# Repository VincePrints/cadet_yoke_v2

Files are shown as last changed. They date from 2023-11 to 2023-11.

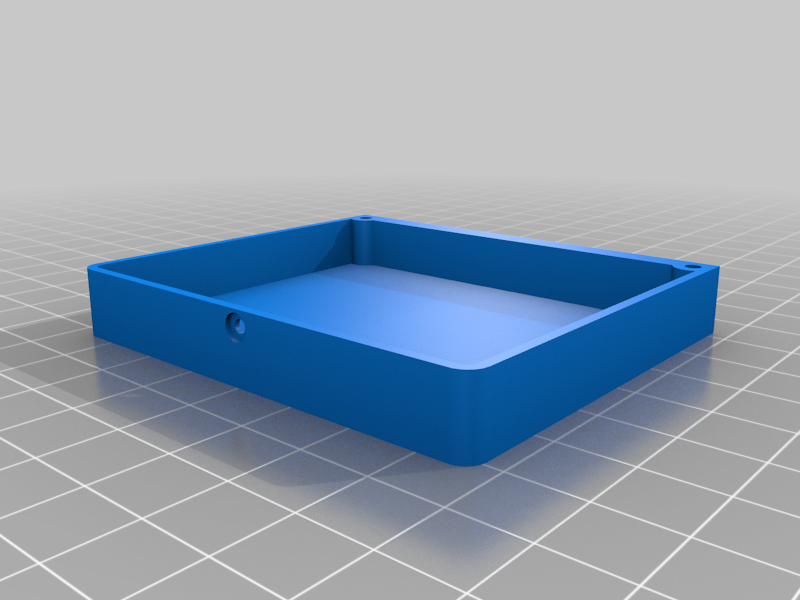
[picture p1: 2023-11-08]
images/Electronics_Housing_Base.png

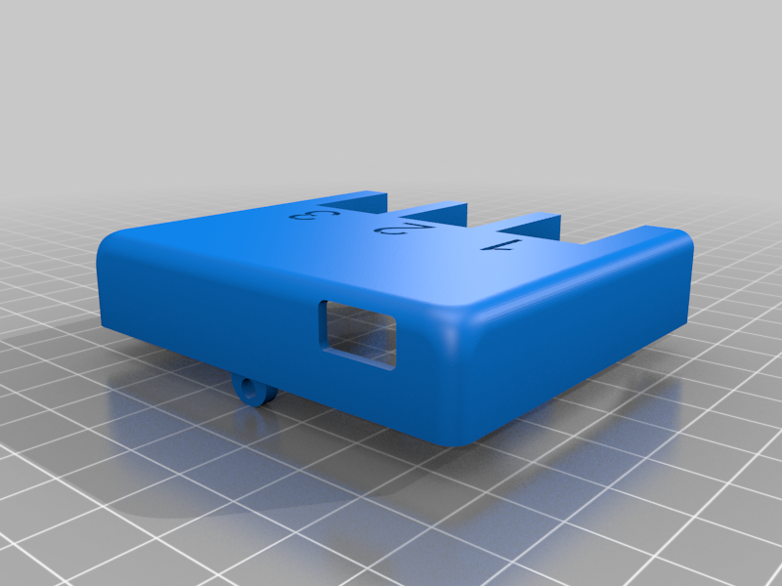
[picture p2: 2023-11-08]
images/Electronics_Housing_Lid.png

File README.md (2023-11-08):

# cadet_yoke_v2

This is an open-source yoke to be used with flight simulators!
- This thing was created by Thingiverse user Vince_Prints, and is licensed under Creative Commons - Attribution - Non-Commercial - Share Alike 

## Build Documentation
- User Guide: [User Guide](./User_Guide.pdf)
- Youtube: [YouTube link](https://www.youtube.com/watch?v=mIO1B-M6C_E)

## 3D Files
- Thingiverse: [Thingiverse link](https://www.thingiverse.com/thing:4884092)
- Printables: [Printables link](https://www.printables.com/model/68980-cadetyoke-v20-open-source-yoke-for-flight-simulato)

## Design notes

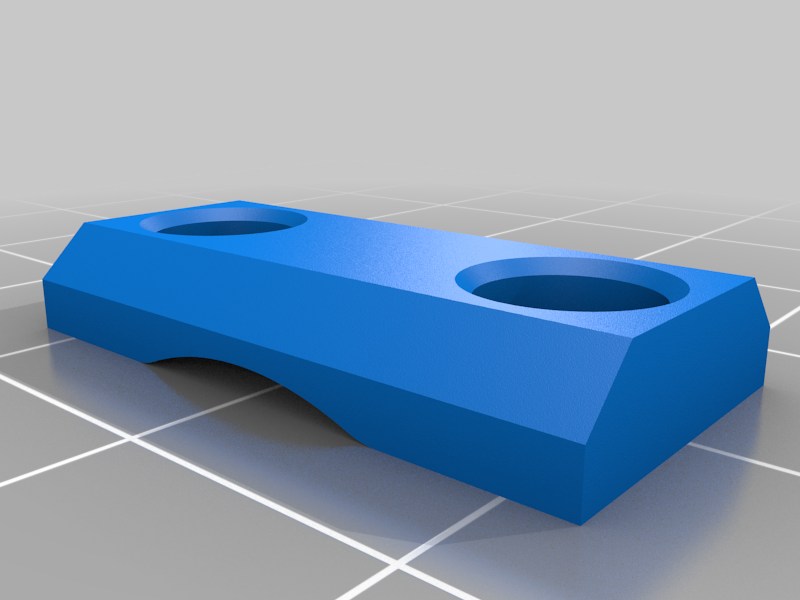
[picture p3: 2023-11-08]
images/Collar_Clip.png

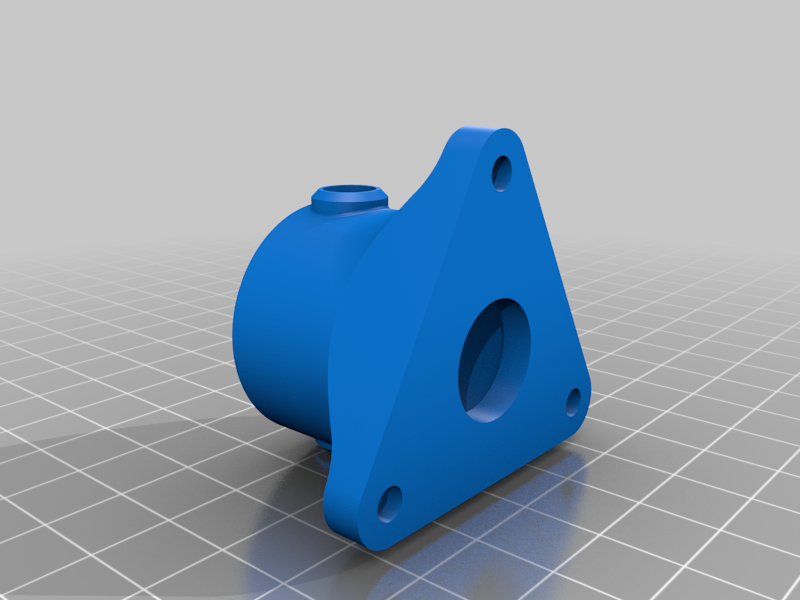
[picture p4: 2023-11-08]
images/Controller_Mount.png

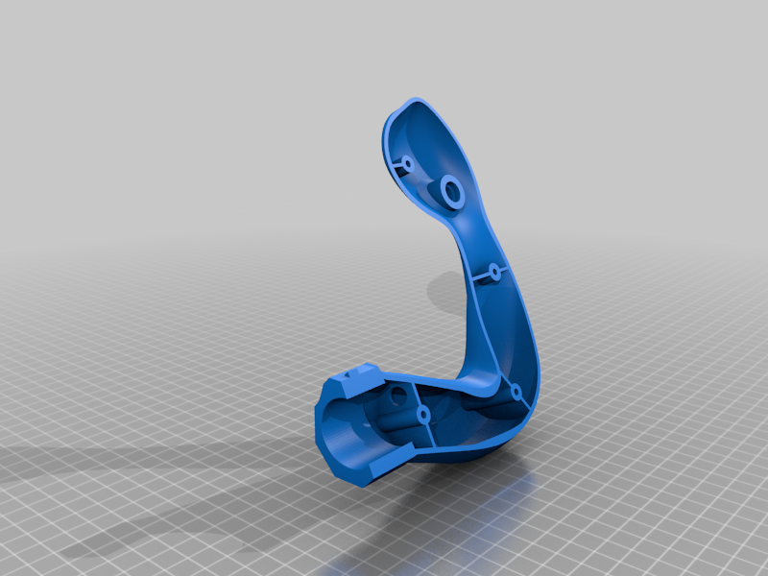
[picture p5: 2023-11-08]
images/Controller_RB.png

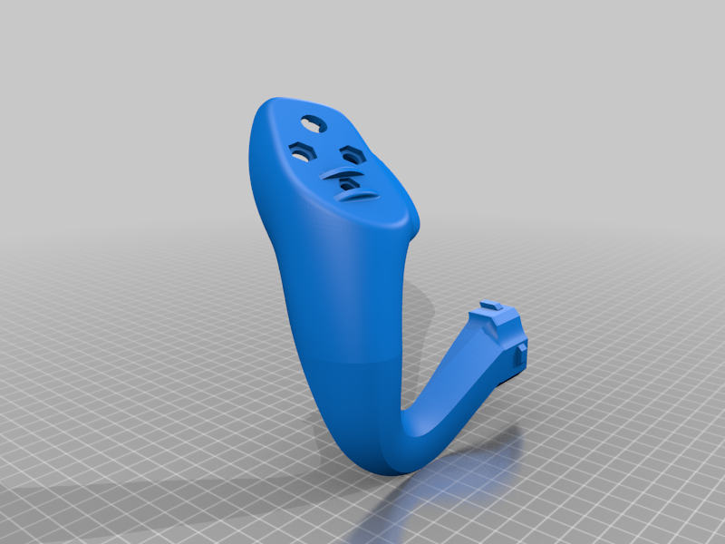
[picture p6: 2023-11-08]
images/Controller_LF.png

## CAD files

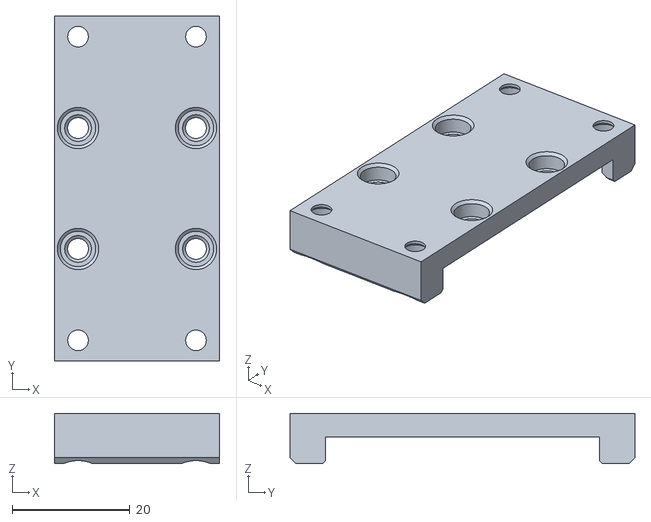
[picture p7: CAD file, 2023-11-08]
3D files/Linear_Rail_Mount.stl
28.0 x 58.5 x 8.50

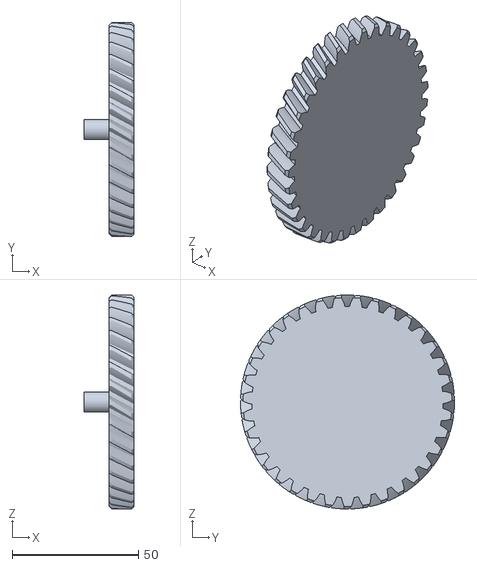
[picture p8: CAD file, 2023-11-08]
3D files/Helical_Pitch_Gear_35R.stl
20.0 x 84.8 x 84.8

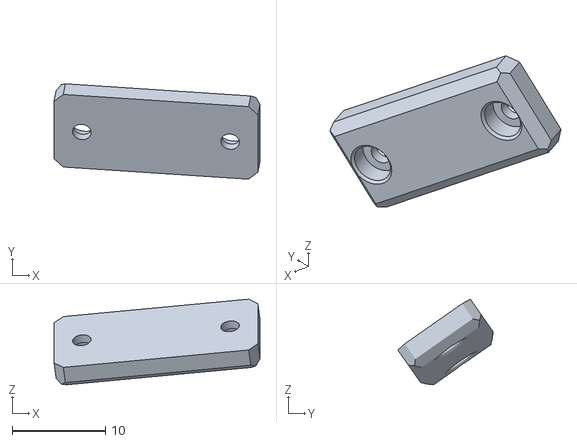
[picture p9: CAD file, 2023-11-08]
3D files/Hat_Switch_Mount.stl
22.1 x 10.2 x 9.18

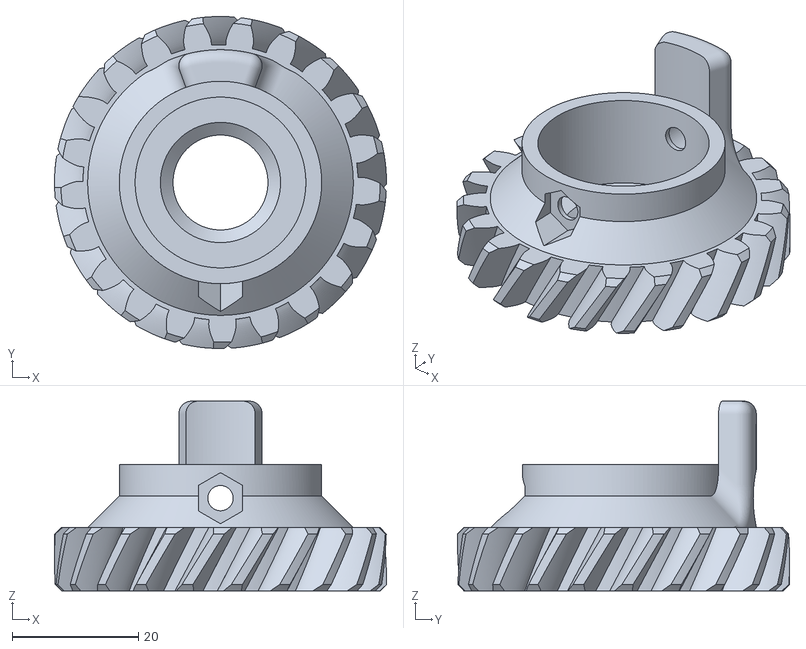
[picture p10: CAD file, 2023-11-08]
3D files/Helical_Roll_Gear_21R.stl
52.5 x 52.5 x 30.0

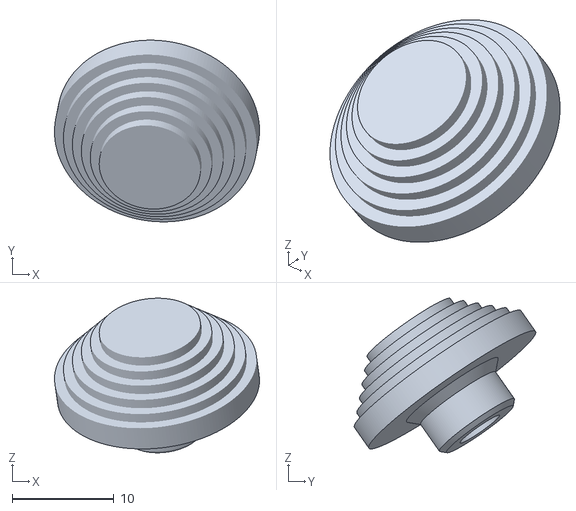
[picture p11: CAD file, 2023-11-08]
3D files/Hat_Switch_Topper.stl
20.2 x 17.9 x 15.2

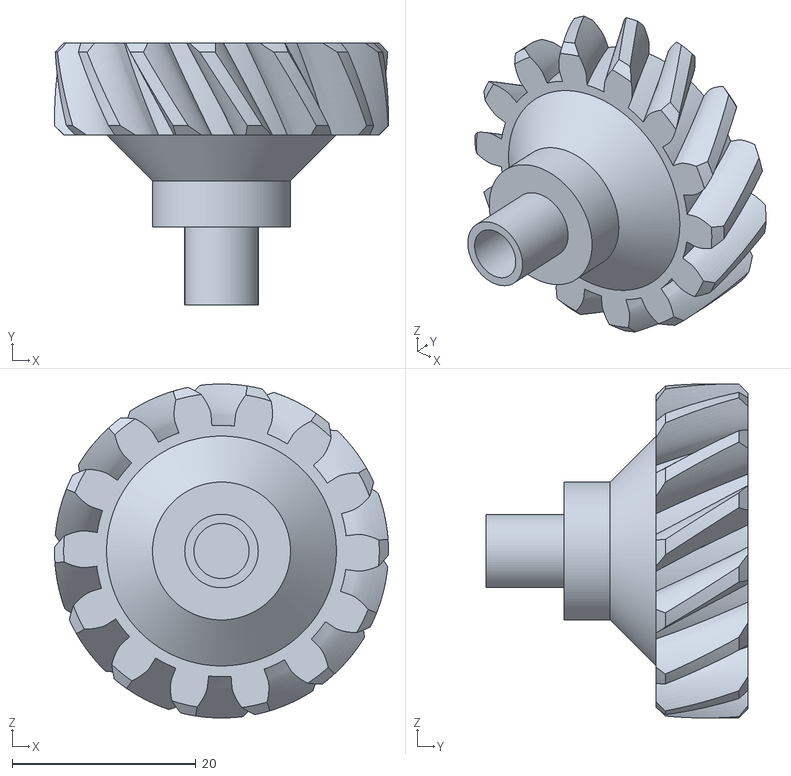
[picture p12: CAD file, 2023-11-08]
3D files/Helical_Roll_Gear__14L.stl
36.3 x 28.5 x 36.3

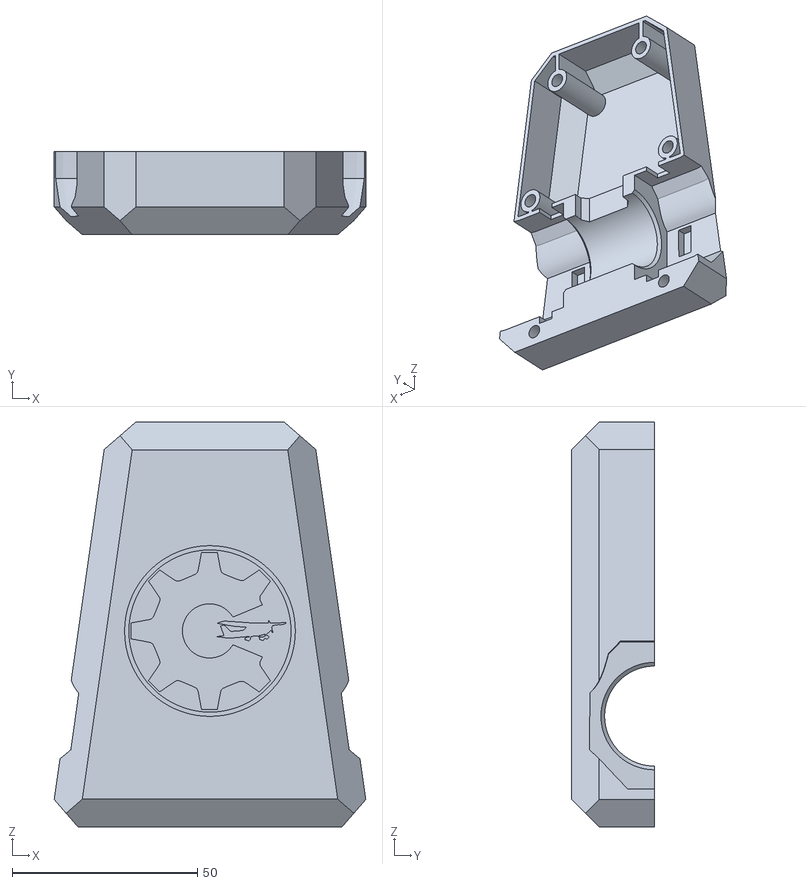
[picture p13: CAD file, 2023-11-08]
3D files/Console_Front.stl
84.1 x 22.5 x 109.3

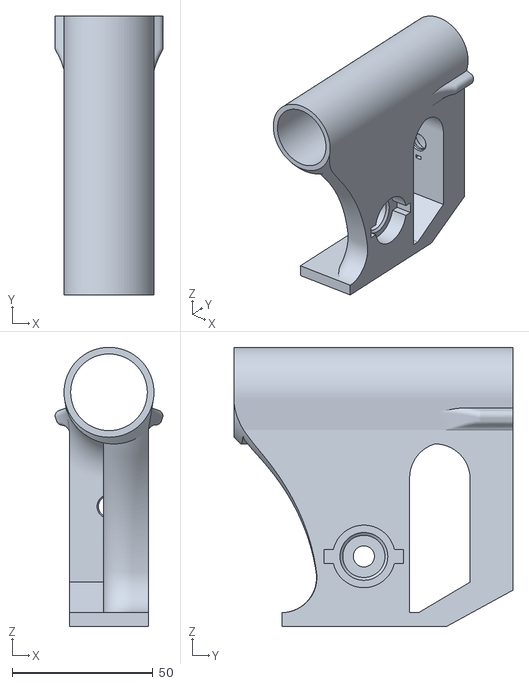
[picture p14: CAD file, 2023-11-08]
3D files/Linear_Rail_Body.stl
38.3 x 99.2 x 99.4

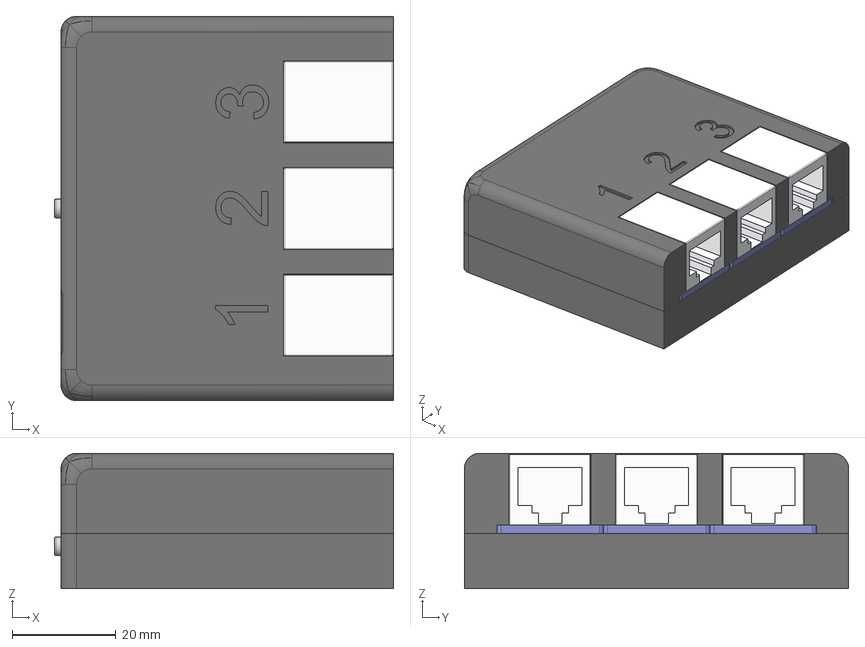
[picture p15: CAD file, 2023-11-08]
3D files/Electronics_Housing.step
65.3 x 74.0 x 26.1 mm
Lid
Base
M2x3 Threaded Insert x 3
M2x4 x 3
CAT5 x 3

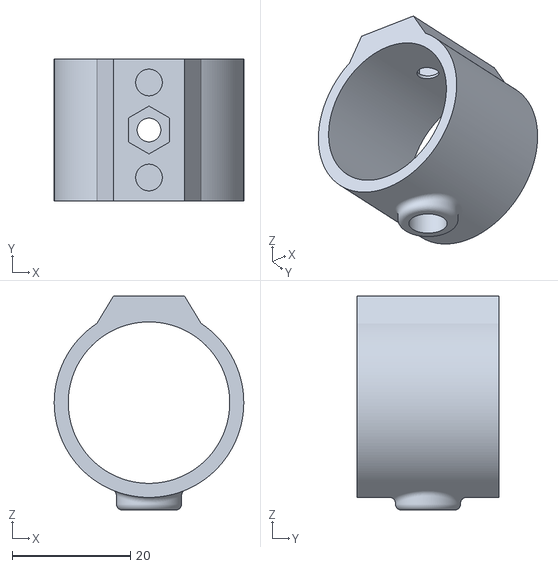
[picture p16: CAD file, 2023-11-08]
3D files/Centering_Collar.stl
32.0 x 24.0 x 36.1

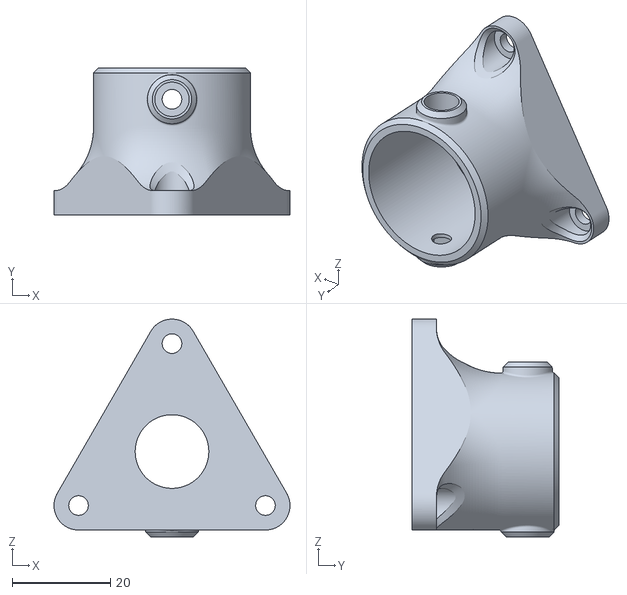
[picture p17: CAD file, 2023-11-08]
3D files/Controller_Mount.stl
48.1 x 30.0 x 44.4

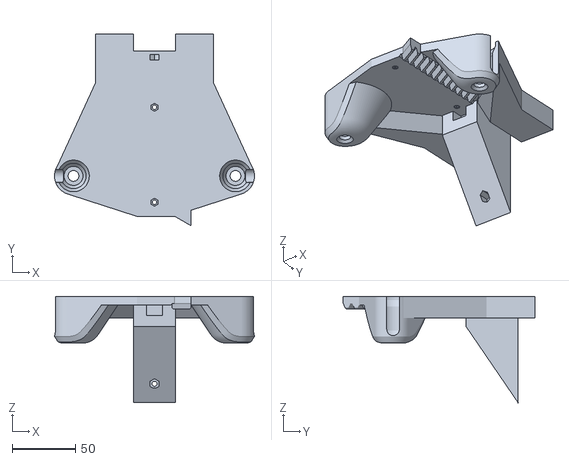
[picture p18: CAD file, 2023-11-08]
3D files/Base_Front.stl
158.0 x 151.4 x 84.0

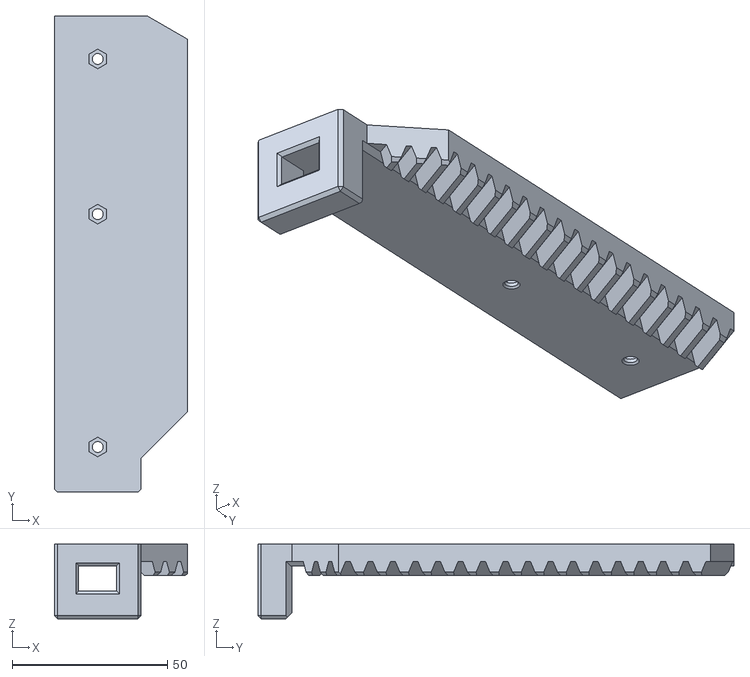
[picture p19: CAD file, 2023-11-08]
3D files/Base_Rear.stl
43.0 x 153.3 x 24.0

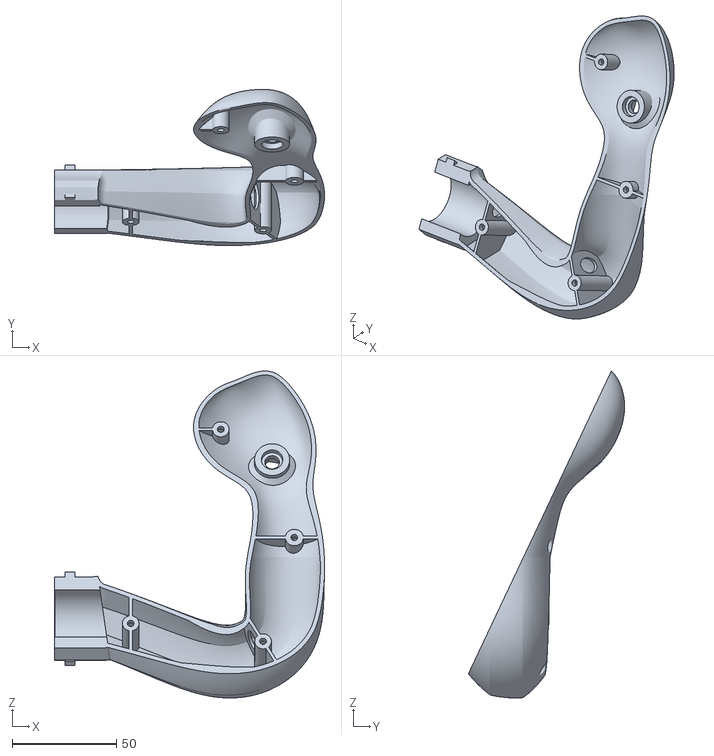
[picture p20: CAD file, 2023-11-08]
3D files/Controller_RB.stl
129.5 x 74.8 x 156.7

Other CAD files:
3D files/Console_Back.stl
3D files/Electronics_Housing_Lid.stl
3D files/Base_Guide.stl
3D files/Collar_Clip.stl
3D files/Controller_LB.stl
3D files/Electronics_Housing_Base.stl

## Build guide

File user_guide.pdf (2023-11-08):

CadetYokev2 Information

# Table of Contents:

Section: | Page #:
Code | 2
Bill of Materials (BOM) | 2 - 3
BOM Notes | 4
Wiring Diagram | 5 - 9
Printed Part Information | 10 - 31

BOM

# Arduino Code:

https://create.arduino.cc/editor/vince_prints/197730fc-074d-4160-bb42-757c4dfc1fe1/preview (https://create.arduino.cc/editor/vince_prints/197730fc-074d-4160-bb42-757c4dfc1fe1/preview)

Part: | Quantity: | Link: | Reused?:
Screws
M4 Nut | 8 | Amazon (https://www.amazon.com/gp/product/B071KBVZVV/ref=ppx_yo_dt_b_search_asin_title?ie=UTF8&psc=1) | All Projects
M4x30 (Socket Cap) | 3 | Amazon (https://www.amazon.com/gp/product/B071KBVZVV/ref=ppx_yo_dt_b_search_asin_title?ie=UTF8&psc=1) | All Projects
M4x10 (Socket Cap) | 3 | Amazon (https://www.amazon.com/gp/product/B071KBVZVV/ref=ppx_yo_dt_b_search_asin_title?ie=UTF8&psc=1) | All Projects
M4x18 (Socket Cap) | 2 | Amazon (https://www.amazon.com/gp/product/B071KBVZVV/ref=ppx_yo_dt_b_search_asin_title?ie=UTF8&psc=1) | All Projects
M3 Nut | 5 | Amazon (https://www.amazon.com/gp/product/B071KBVZVV/ref=ppx_yo_dt_b_search_asin_title?ie=UTF8&psc=1) | All Projects
M3x8 (Socket Cap) | 11 | Amazon (https://www.amazon.com/gp/product/B071KBVZVV/ref=ppx_yo_dt_b_search_asin_title?ie=UTF8&psc=1) | All Projects
M3x5 (Socket Cap) | 12 | Amazon (https://www.amazon.com/gp/product/B071KBVZVV/ref=ppx_yo_dt_b_search_asin_title?ie=UTF8&psc=1) | All Projects
M3x4 (Socket Cap) | 6 | Amazon (https://www.amazon.com/gp/product/B071KBVZVV/ref=ppx_yo_dt_b_search_asin_title?ie=UTF8&psc=1) | All Projects
M3x8 Threaded Brass Insert | 6 | Amazon (https://www.amazon.com/gp/product/B0784VYCYY/ref=ppx_yo_dt_b_search_asin_title?ie=UTF8&psc=1) | All Projects
M3x4 Threaded Brass Insert | 8 | Amazon (https://www.amazon.com/gp/product/B0784VYCYY/ref=ppx_yo_dt_b_search_asin_title?ie=UTF8&psc=1) | All Projects
M3x3 Threaded Brass Insert | 6 | Amazon (https://www.amazon.com/gp/product/B0784VYCYY/ref=ppx_yo_dt_b_search_asin_title?ie=UTF8&psc=1) | All Projects
M2x8 (Socket Cap) | 2 | Amazon (https://www.amazon.com/gp/product/B071KBVZVV/ref=ppx_yo_dt_b_search_asin_title?ie=UTF8&psc=1)
M2x4 (Socket Cap) | 3 | Amazon (https://www.amazon.com/gp/product/B071KBVZVV/ref=ppx_yo_dt_b_search_asin_title?ie=UTF8&psc=1) | All Projects
M2x3 Threaded Brass Insert | 5 | Amazon (https://www.amazon.com/gp/product/B0784VYCYY/ref=ppx_yo_dt_b_search_asin_title?ie=UTF8&psc=1) | All Projects

Electronics
Arduino Pro Micro | 1 | Amazon (https://www.amazon.com/gp/product/B07FXCTVQP/ref=ppx_yo_dt_b_search_asin_title?ie=UTF8&psc=1) | Salvaged from CadetYokev1
50x70mm Perf Board | 1 | Amazon (https://www.amazon.com/dp/B072Z7Y19F/ref=cm_sw_em_r_mt_dp_XC1HMP3KM1KTHSQAH6XX?_encoding=UTF8&psc=1) | All Projects
Female Pin Headers | 1 | Amazon (https://www.amazon.com/gp/product/B07CGGSDWF/ref=ppx_yo_dt_b_search_asin_title?ie=UTF8&psc=1) | All Projects
Large Momentary Pushbutton | 1 | Amazon (https://www.amazon.com/gp/product/B079D3ZZ1L/ref=ppx_yo_dt_b_search_asin_title?ie=UTF8&psc=1) | CadetThrottle

BOM

Small Momentary Pushbutton | 6 | Amazon (https://www.amazon.com/gp/product/B0752RMB7Q/ref=ppx_yo_dt_b_search_asin_title?ie=UTF8&psc=1) | Salvaged from CadetYokev1
Two-way Momentary Toggle Switch | 2 | Amazon (https://www.amazon.com/gp/product/B07VHCB1Q4/ref=ppx_yo_dt_b_search_asin_title?ie=UTF8&psc=1) | Salvaged from CadetYokev1
5-way Navigation Switch | 1 | Amazon (https://www.amazon.com/gp/product/B00E6QM2F0/ref=ppx_yo_dt_b_search_asin_title?ie=UTF8&psc=1)
Potentiometer (any value) | 2 | Amazon (https://www.amazon.com/gp/product/B07VJ57LJF/ref=ppx_yo_dt_b_search_asin_title?ie=UTF8&psc=1) | Salvaged from CadetYokev1
Diode (1N4007) | 16 | Amazon (https://www.amazon.com/gp/product/B00W17LOBO/ref=ppx_yo_dt_b_asin_title_o05_s00?ie=UTF8&psc=1)
10 ft. (~3m) CAT5e Cable | 1 | Amazon (https://www.amazon.com/Mediabridge-Ethernet-Cable-Feet-31-399-10X/dp/B003O973OA)
RJ45 8-pin Connector and Breakout Board | 3 | Amazon (https://www.amazon.com/gp/product/B08HGS5G8N/ref=ppx_yo_dt_b_asin_title_o08_s00?ie=UTF8&psc=1)
RJ45 Crimmping tool | 1 | Amazon (https://www.amazon.com/gp/product/B08DHJBLXQ/ref=ppx_yo_dt_b_asin_title_o07_s00?ie=UTF8&psc=1)
RJ45 Connectors | 3 | Amazon (https://www.amazon.com/gp/product/B08DHJBLXQ/ref=ppx_yo_dt_b_asin_title_o07_s00?ie=UTF8&psc=1)
RJ45 Covers | 3 | Amazon (https://www.amazon.com/gp/product/B08DHJBLXQ/ref=ppx_yo_dt_b_asin_title_o07_s00?ie=UTF8&psc=1)
Wire [1] | | Amazon (https://www.amazon.com/gp/product/B07G2GLKMP/ref=ppx_yo_dt_b_search_asin_title?ie=UTF8&psc=1) | All Projects
Mechanical Components
Linear Rail (250mm, H-Type) | 1 | Amazon (https://www.amazon.com/gp/product/B07GBNTJW3/ref=ppx_yo_dt_b_search_asin_title?ie=UTF8&psc=1) | Salvaged from CadetYokev1
Ball Bearings (608-2RS) | 2 | Amazon (https://www.amazon.com/gp/product/B07R7PR72H/ref=ppx_yo_dt_b_search_asin_title?ie=UTF8&psc=1) | Salvaged from CadetYokev1
3/4 in. PVC Pipe (350mm Length) [2] | 1
3/4 in. PVC Pipe (70mm Length) [3] | 1 | | Salvaged from CadetYokev1
Exercise Band (Green) | 1 | Amazon (https://www.amazon.com/gp/product/B0000AJ04V/ref=ppx_yo_dt_b_search_asin_title?ie=UTF8&th=1)
Zip ties [4] | | | All Projects
Mounting Clamps [5] | 2 | Amazon (https://www.amazon.com/gp/product/B093ND5KN5/ref=ppx_yo_dt_b_asin_title_o09_s00?ie=UTF8&th=1)

Notes

[1] User Preference
[2] !!!WARNING!!! In the US, 3/4 inch (19.05mm) describes the INNER diameter of the pipe, the outer diameter is 1.05 inches (26.67mm).
[3] !!!WARNING!!! In the US, 3/4 inch (19.05mm) describes the INNER diameter of the pipe, the outer diameter is 1.05 inches (26.67mm).
[4] User Preference
[5] User Preference

5-way tactile switch pinout

Notice spacing

Arduino Micro

Pin
Numbers

Button/Switch Reference

Pins

Common

(Shared by
both pins)

Pins

Signal
5V

GND

Diode Direction Reference

CAT5e Color Reference

In this guide, color
saturation will
indicate spiral
verses solid colors.

Example:

Spiral Orange:

Orange:

1
2

3

4
5

6

7 8 9 10 14

# #1 (Left Side)

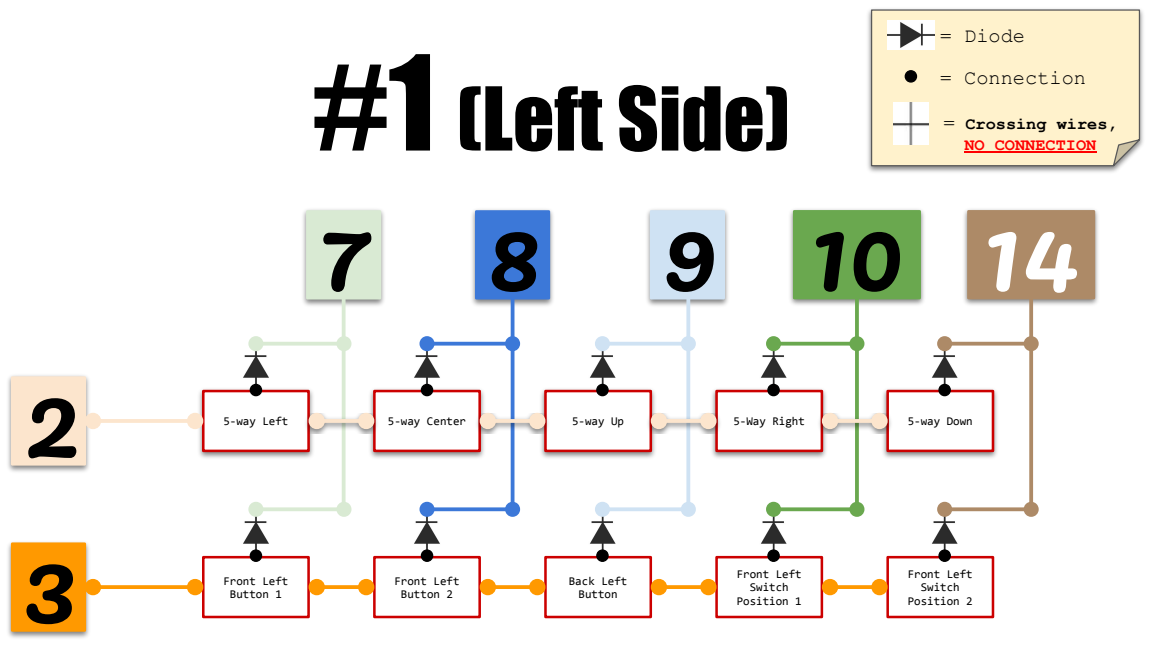
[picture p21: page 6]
5-way Left; 5-way Center; 5-way Up; 5-Way Right; 5-way Down; Front Left Button 1; Front Left Button 2; Back Left Button; Front Left Switch Position 1; Front Left Switch Position 2; = Diode; = Connection; = Crossing wires,; NO CONNECTION

15 16
45

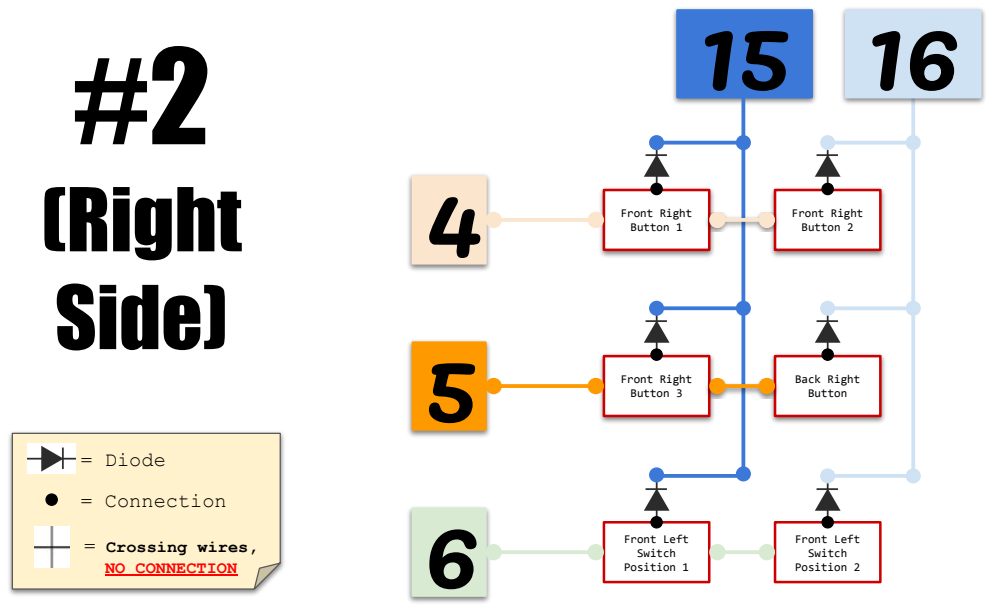
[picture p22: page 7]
Front Right Button 1; Front Right Button 2; Front Right Button 3; Back Right Button; (Right Side); = Diode; NO CONNECTION; Front Left Switch Position 1; Front Left Switch; Position 2

= Connection = Crossing wires,

# #3 (Pitch + Roll)

Roll | Pitch

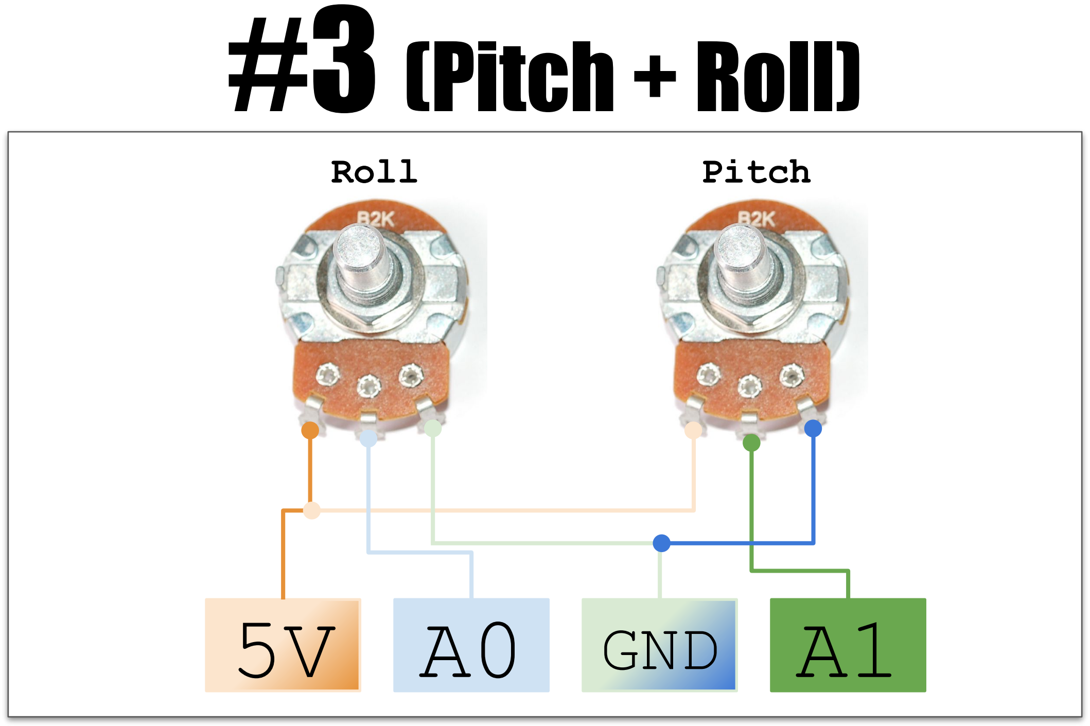
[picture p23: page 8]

5V | A0 | GND
A1

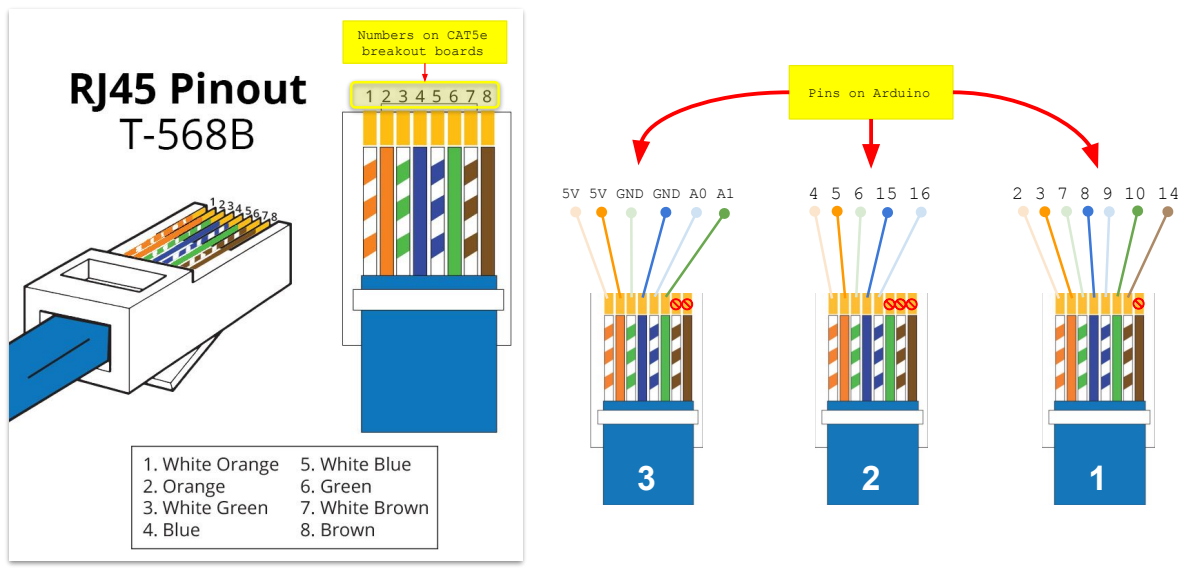
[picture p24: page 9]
5V 5V GND GND A0 A1; Numbers on CAT5e breakout boards

Pins on Arduino

Part: | Page #: | Approximate Mass (grams):
Base_Back | 11 | 36.15
Base_Front | 12 | 154.57
Base_Guide | 13 | 25.84
Centering_Collar | 14 | 7.65
Collar_Clip | 15 | 1.05
Console_Back | 16 | 52.10
Console_Front | 17 | 47.35
Controller_LB | 18 | 84.41
Controller_LF | 19 | 85.31
Controller_Mount | 20 | 13.66
Controller_RB | 21 | 84.41
Controller_RF | 22 | 83.53
Electronics_Housing_Base | 23 | 16.70
Electronics_Housing_Lid | 24 | 16.14
Hat_Switch_Mount | 25 | 0.72
Hat_Switch_Topper | 26 | 2.65
Helical_Pitch_Gear_35R | 27 | 29.33
Helical_Roll_Gear_14L | 28 | 7.00
Helical_Roll_Gear_21R | 29 | 14.19
Linear_Rail_Body | 30 | 87.25
Linear_Rail_Mount | 31 | 5.89
| Total Mass (grams): | 855.90

Base_Back (36.15g)
Filament: PETG
Layer Height: 0.2
Perimeters: 3
Infill: 15%
Supports: On build plate only

Print Orientation

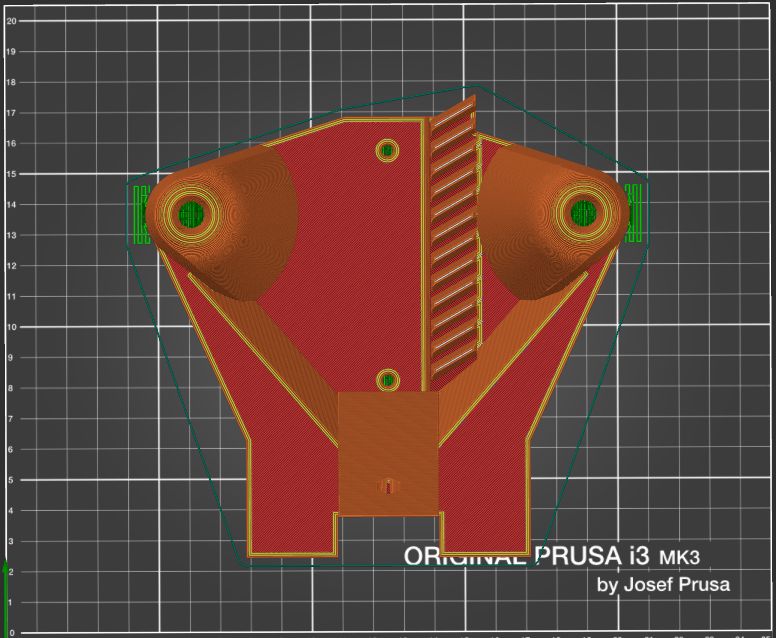
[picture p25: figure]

Base_Front (154.57g)
Filament: PETG
Layer Height: 0.2
Perimeters: 3
Infill: 15%
Supports: On build plate only

Print Orientation

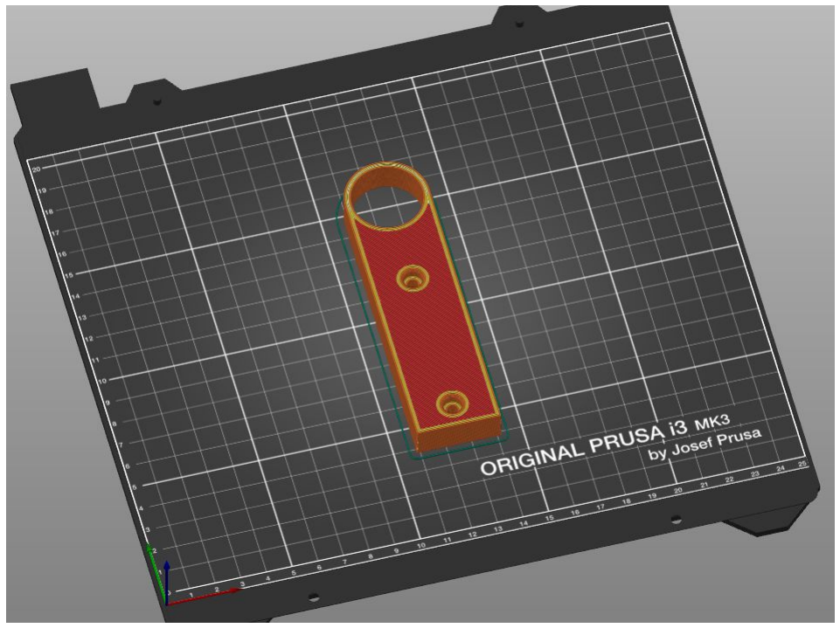
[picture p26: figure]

Base_Guide (25.84g)
Filament: PETG
Layer Height: 0.2
Perimeters: 3
Infill: 15%
Supports: None

Print Orientation

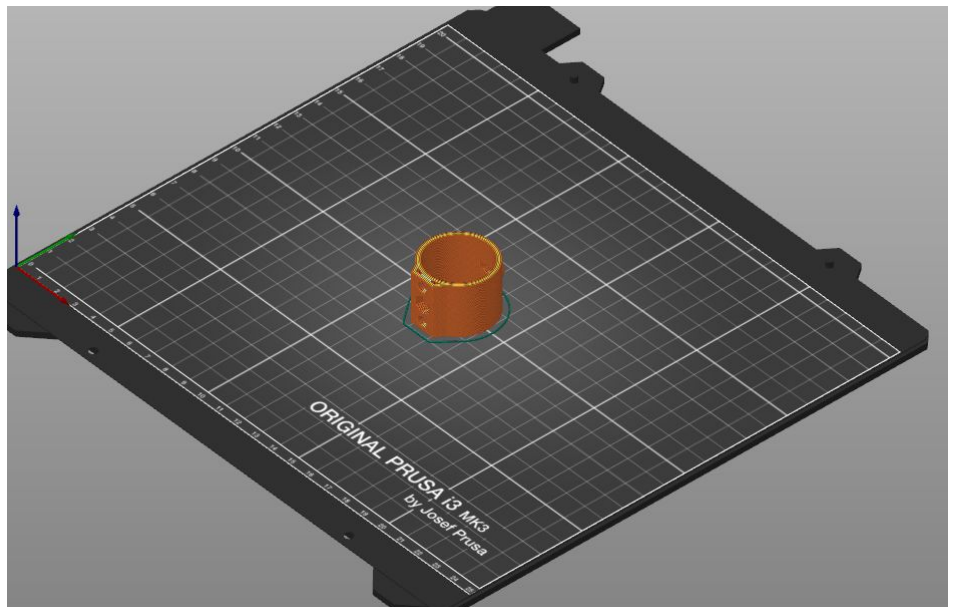
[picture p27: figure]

Centering_Collar (7.65g)
Filament: PETG
Layer Height: 0.2
Perimeters: 3
Infill: 15%
Supports: None

Print Orientation

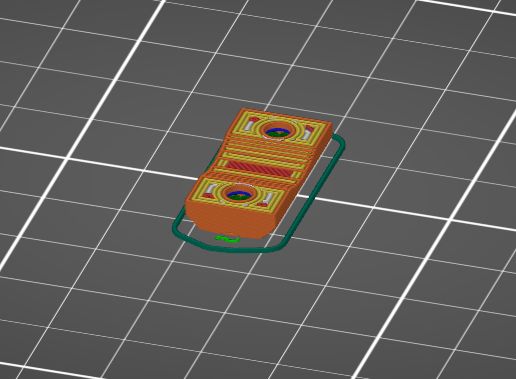
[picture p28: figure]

Collar_Clip (1.05g)
Filament: PETG
Layer Height: 0.2
Perimeters: 3
Infill: 15%
Supports: On build plate only

Print Orientation

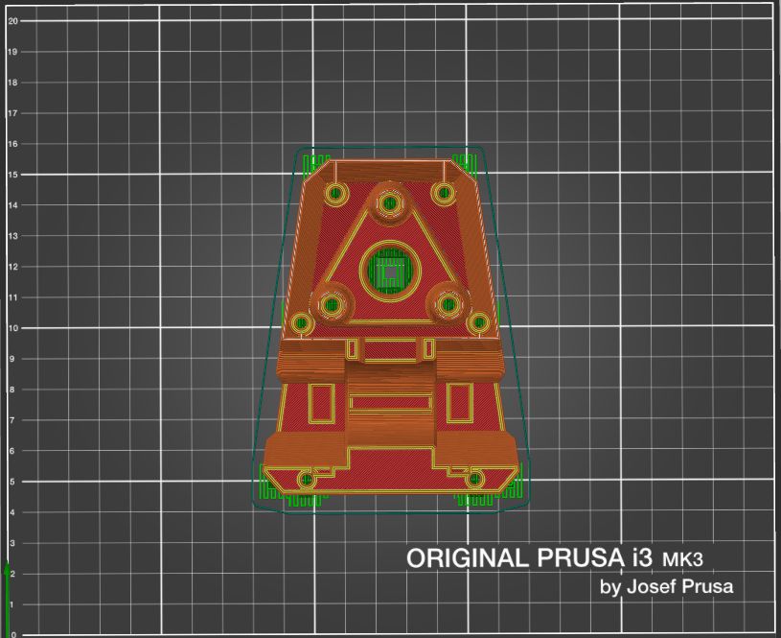
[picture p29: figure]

Console_Back (52.10g)
Filament: PETG
Layer Height: 0.2
Perimeters: 3
Infill: 15%
Supports: On build plate only

Print Orientation

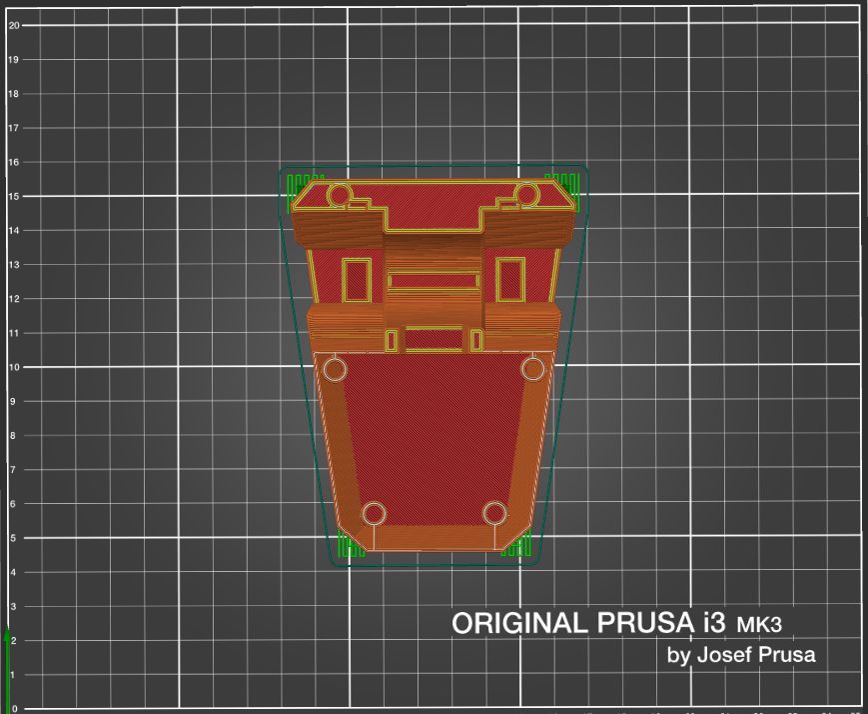
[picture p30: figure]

Console_Front (47.35g)
Filament: PETG
Layer Height: 0.2
Perimeters: 3
Infill: 15%
Supports: None

Print Orientation

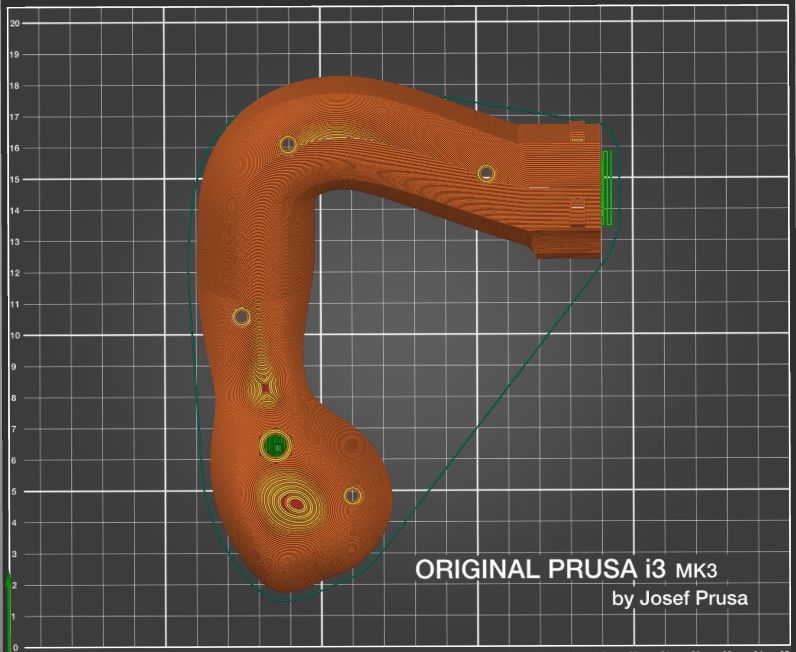
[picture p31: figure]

Controller_LB (84.41g)
Filament: PETG
Layer Height: 0.2
Perimeters: 3
Infill: 15%
Supports: On build plate only

Print Orientation

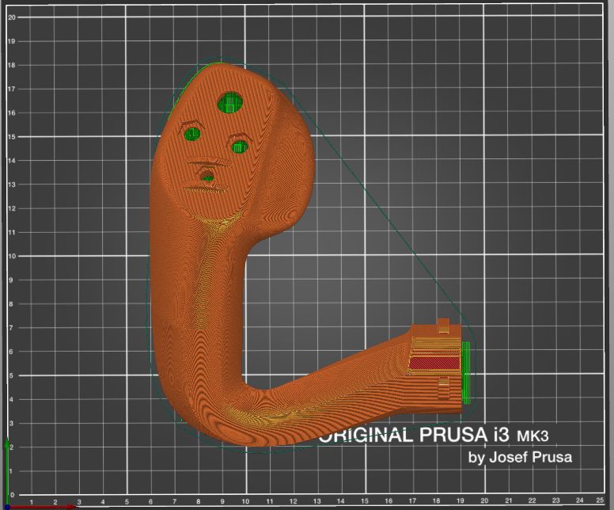
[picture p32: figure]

Controller_LF (85.31g)
Filament: PETG
Layer Height: 0.2
Perimeters: 3
Infill: 15%
Supports: On build plate only

Print Orientation

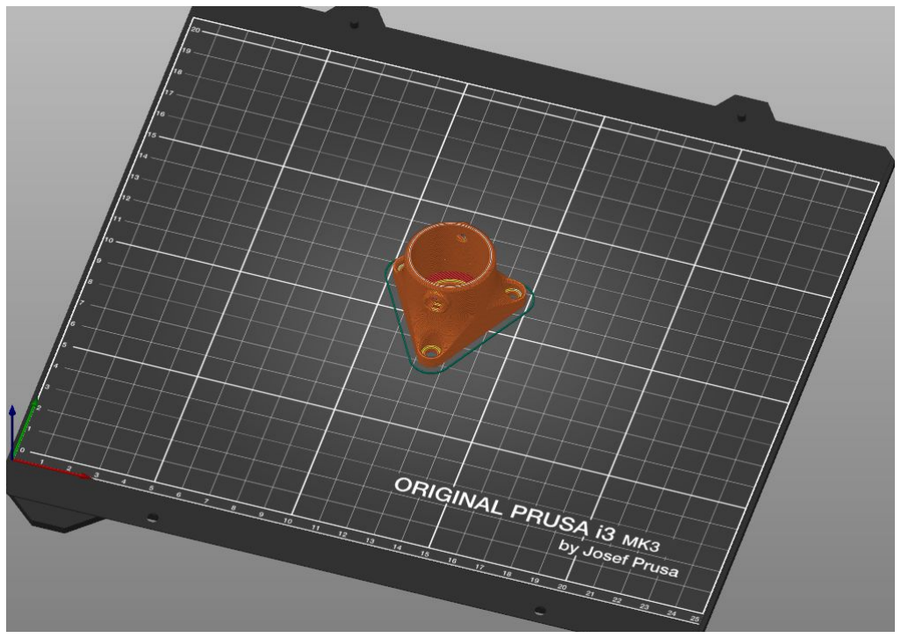
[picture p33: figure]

Controller_Mount (13.66g)
Filament: PETG
Layer Height: 0.2
Perimeters: 3
Infill: 15%
Supports: None

Print Orientation

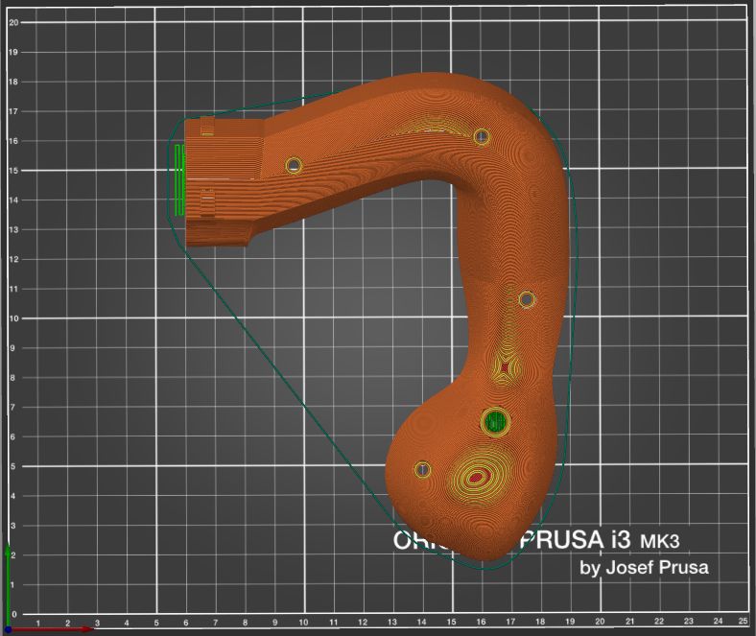
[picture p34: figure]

Controller_RB (84.41g)
Filament: PETG
Layer Height: 0.2
Perimeters: 3
Infill: 15%
Supports: On build plate only

Print Orientation

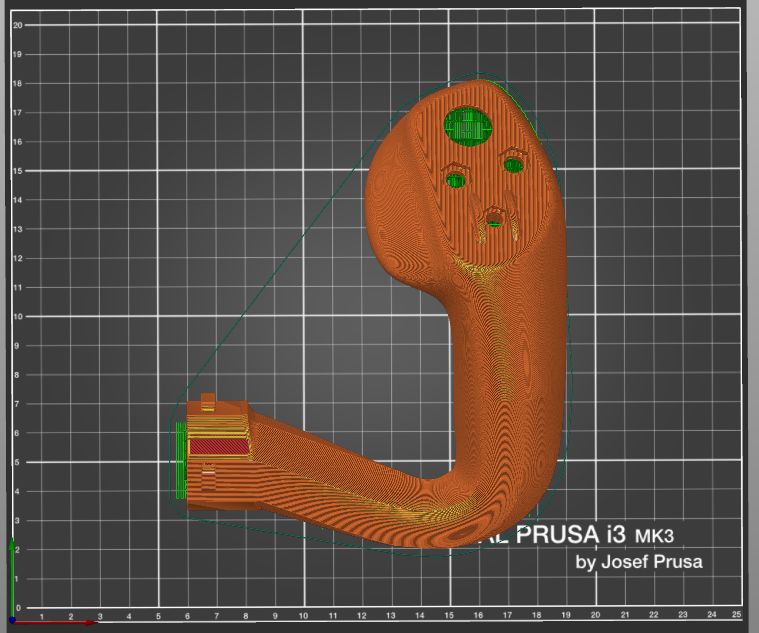
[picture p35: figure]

Controller_RF (83.53g)
Filament: PETG
Layer Height: 0.2
Perimeters: 3
Infill: 15%
Supports: On build plate only

Print Orientation

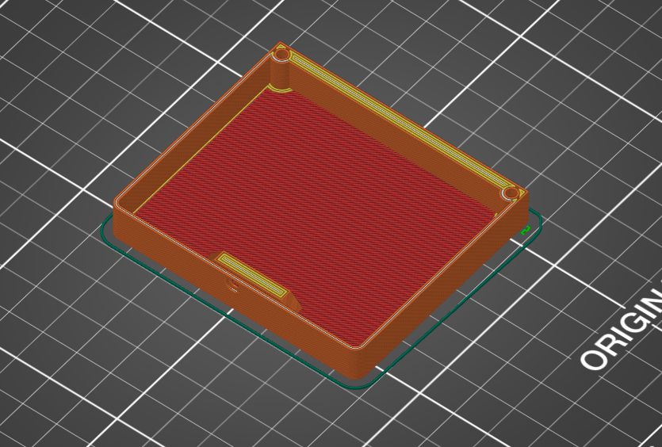
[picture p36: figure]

Electronics_Housing_Base (16.70g) Filament: PETG
Layer Height: 0.2
Perimeters: 3
Infill: 15%
Supports: On build plate only

Print Orientation

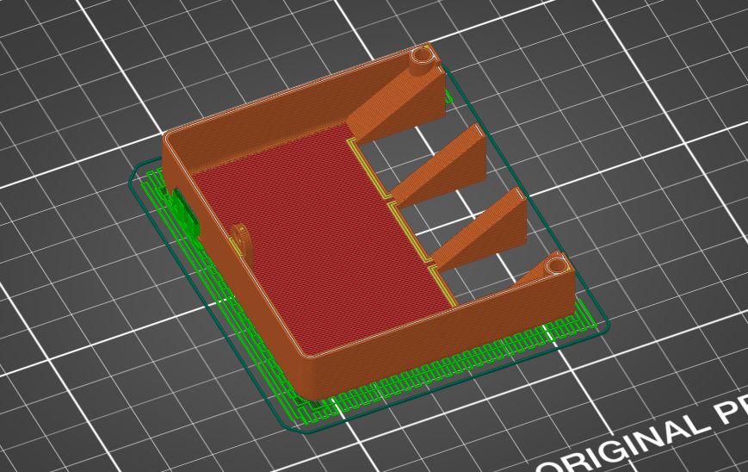
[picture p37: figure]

Electronics_Housing_Lid (16.14g) Filament: PETG
Layer Height: 0.2
Perimeters: 3
Infill: 15%
Supports: On build plate only

Print Orientation

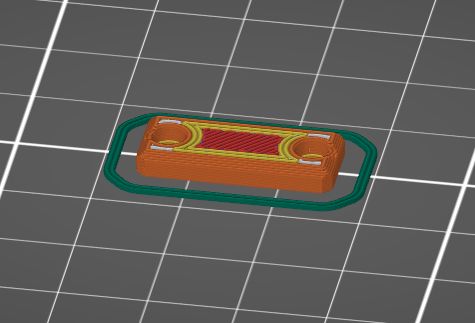
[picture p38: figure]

Hat_Switch_Mount (0.72g)
Filament: PETG
Layer Height: 0.2
Perimeters: 3
Infill: 15%
Supports: On build plate only

Print Orientation

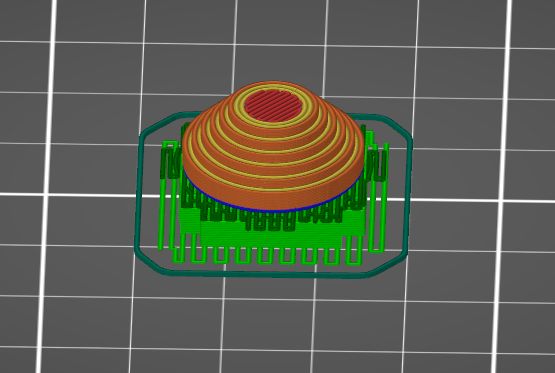
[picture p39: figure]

Hat_Switch_Topper (2.65g)
Filament: PETG
Layer Height: 0.2
Perimeters: 3
Infill: 15%
Supports: On build plate only

Print Orientation

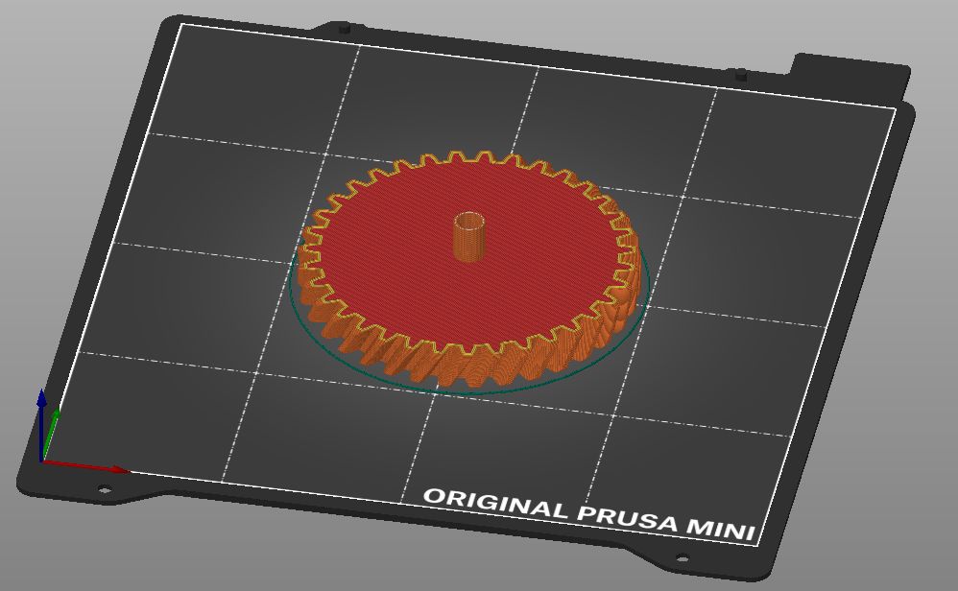
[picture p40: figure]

Helical_Pitch_Gear_35R(29.33g) Filament: PETG
Layer Height: 0.2
Perimeters: 3
Infill: 15%
Supports: None

Print Orientation

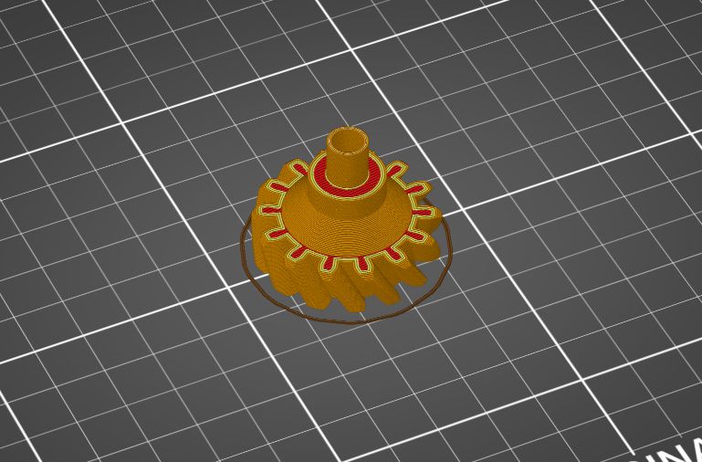
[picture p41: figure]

Helical_Roll_Gear_14L (7.00g) Filament: PETG
Layer Height: 0.2
Perimeters: 3
Infill: 15%
Supports: None

Print Orientation

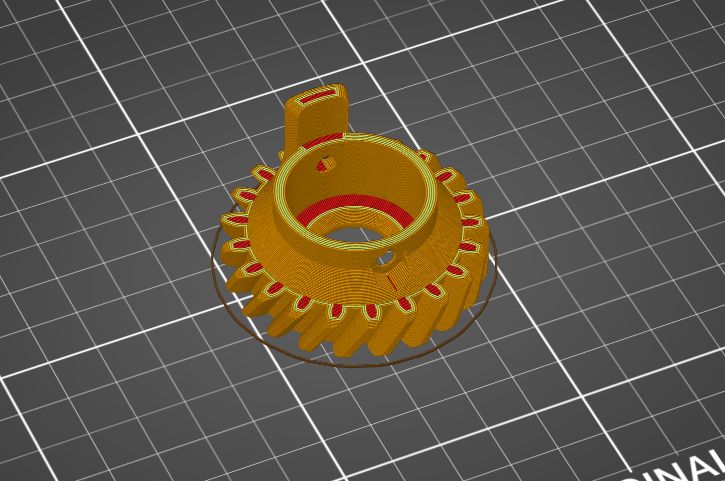
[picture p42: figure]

Helical_Roll_Gear_21R (14.19g) Filament: PETG
Layer Height: 0.2
Perimeters: 3
Infill: 15%
Supports: None

Print Orientation

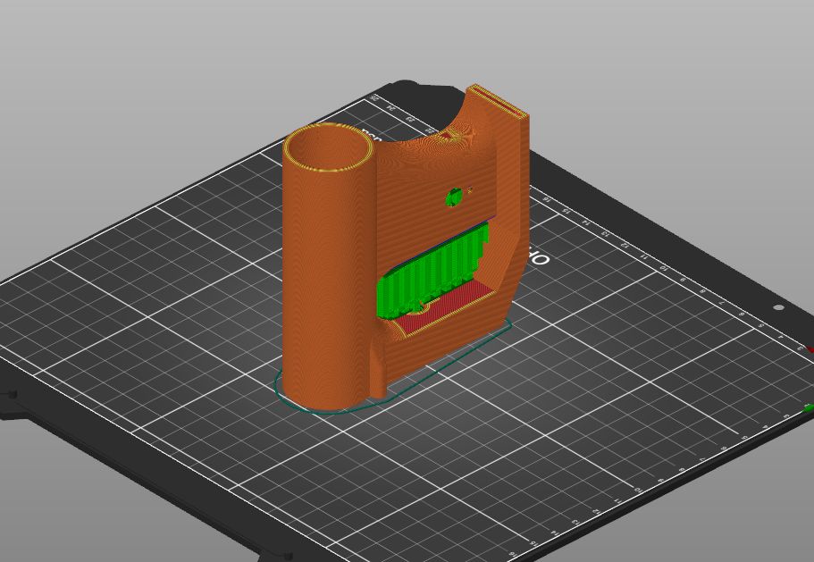
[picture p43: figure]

Linear_Rail_Body (87.25g)
Filament: PETG
Layer Height: 0.2
Perimeters: 3
Infill: 15%
Supports: Everywhere

Print Orientation

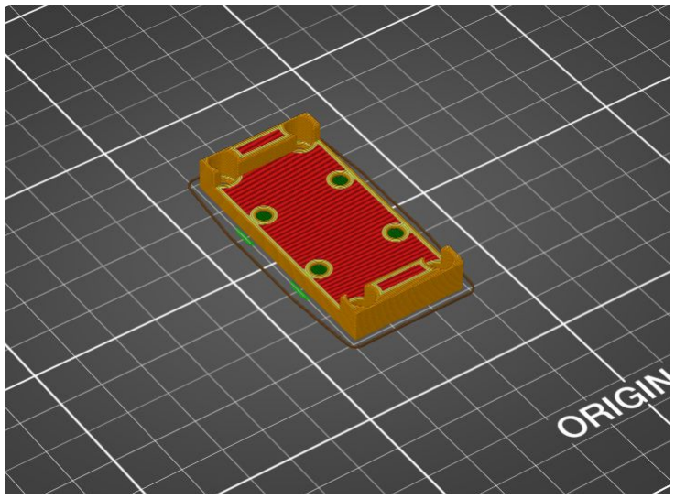
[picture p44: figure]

Linear_Rail_Mount (5.89g)
Filament: PETG
Layer Height: 0.2
Perimeters: 3
Infill: 15%
Supports: On build plate only

Print Orientation
